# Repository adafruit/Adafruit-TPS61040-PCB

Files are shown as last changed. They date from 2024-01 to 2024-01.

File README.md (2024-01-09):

## Adafruit TPS61040 12V Bias Voltage Boost Converter PCB

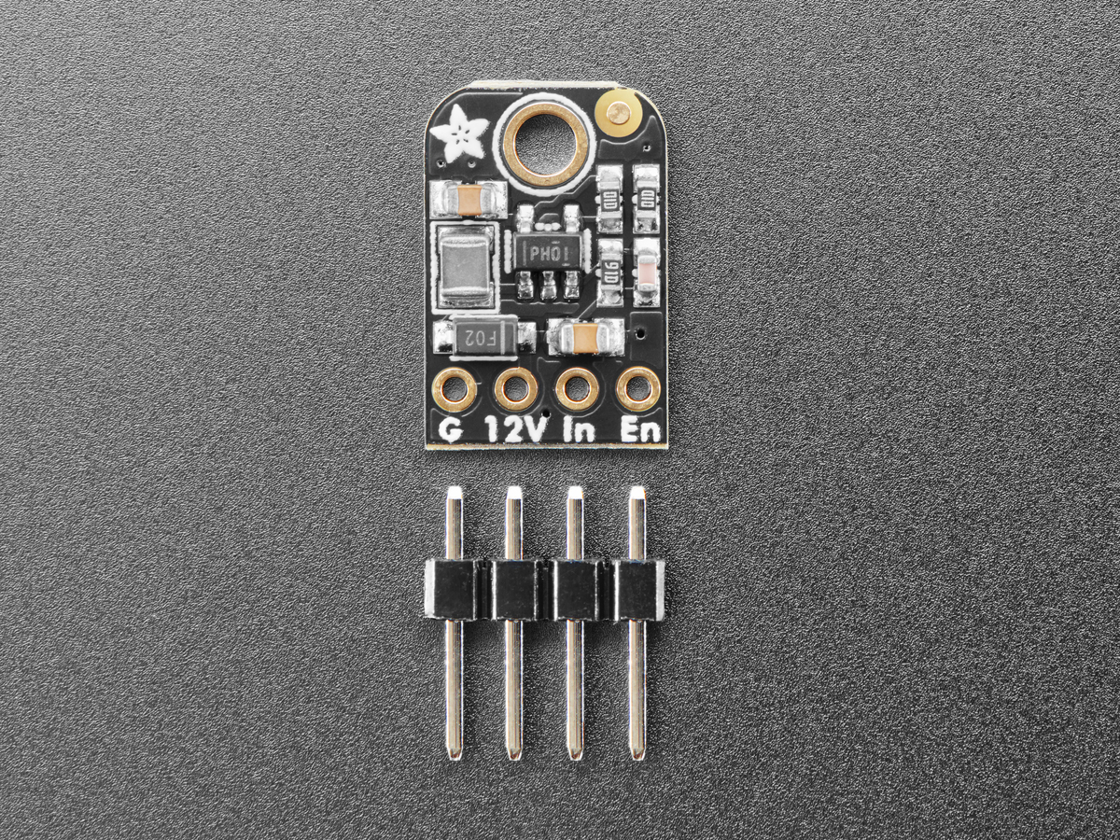
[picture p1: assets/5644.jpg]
<a href="http://www.adafruit.com/products/5644"><br/>
Click here to purchase one from the Adafruit shop</a>

PCB files for the Adafruit TPS61040 12V Bias Voltage Boost Converter. 

Format is EagleCAD schematic and board layout
* https://www.adafruit.com/product/5644

### Description

The Adafruit 12V Bias Voltage Boost Converter uses our new favorite mini-booster, the TI TPS61040, to generate a 12V DC from as little as 3V input. We use this chip a ton in our OLED boards, to generate the 12V bias voltage needed for the displays to function. But there's probably many other times and reasons you may want a high-ish voltage, such as driving an LED string backlight or re-programming FLASH or EEPROM memories.

Note that this board isn't good for high power driving, like solenoids or motors or long analog LED strips. You can get about 40mA out max. But definitely easier than getting a separate 12V supply when just a small amount of current is needed and you've already got 3.3 or 5V on the board.

You get one fully assembled breakout with a TPS61040 and required passive components, and a small bit of header. Give 2 to 6V DC on the IN and Ground pins. Then you'll have 12V on the 12V output pin. The Enable pin can be pulled low to disable the output.

### License

Adafruit invests time and resources providing this open source design, please support Adafruit and open-source hardware by purchasing products from [Adafruit](https://www.adafruit.com)!

Designed by Limor Fried/Ladyada for Adafruit Industries.

Creative Commons Attribution/Share-Alike, all text above must be included in any redistribution. 
See license.txt for additional details.

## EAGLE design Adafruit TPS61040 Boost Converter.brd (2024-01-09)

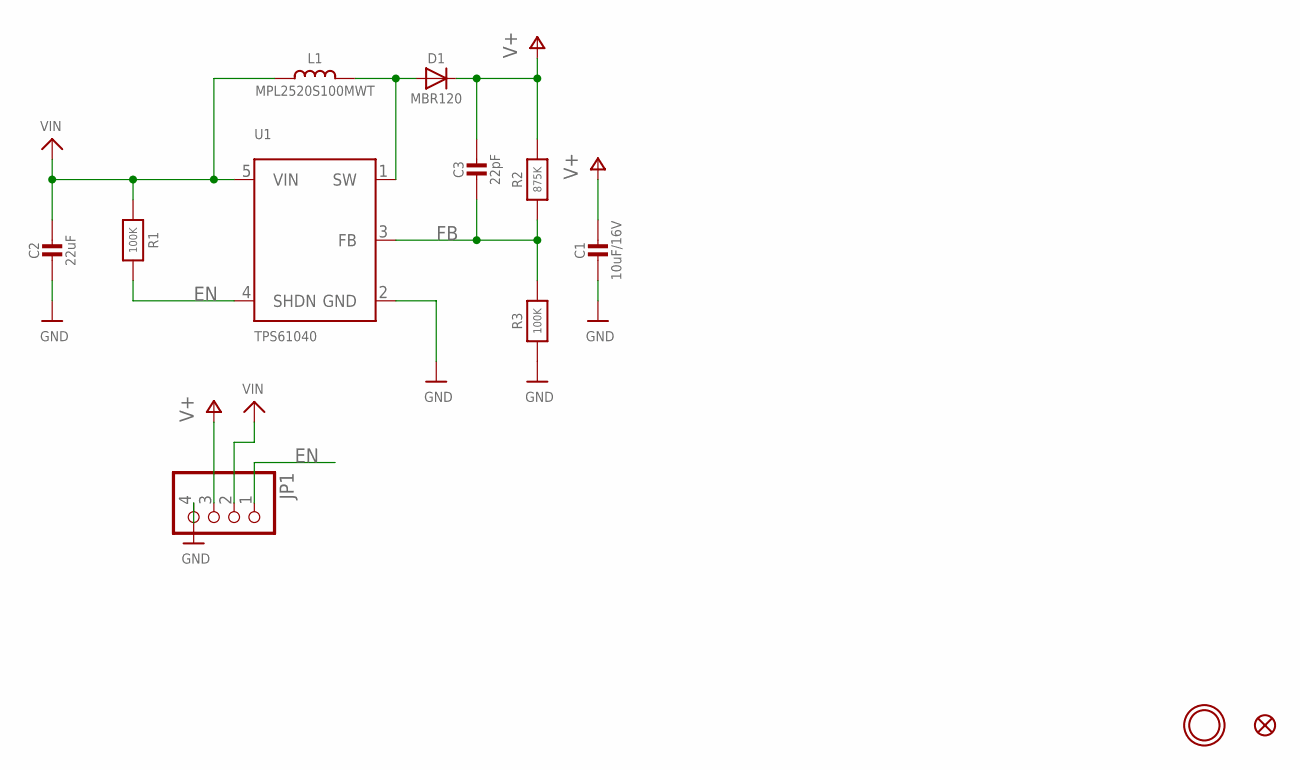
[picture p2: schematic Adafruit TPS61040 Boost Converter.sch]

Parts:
C1: 10uF/16V; 0805-NO
C2: 22uF; 0805-NO
C3: 22pF; 0603-NO
D1: MBR120; SOD-123FL
FID1: FIDUCIAL_1MM
JP1: HEADER-1X4ROUND; 1X04_ROUND
L1: MPL2520S100MWT; INDUCTOR_1007
R1, R3: 100K; 0603-NO
R2: 875K; 0603-NO
U1: TPS61040; SOT23-5
U$9: MOUNTINGHOLE2.5; MOUNTINGHOLE_2.5_PLATED

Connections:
EN: JP1.1, R1.2, U1.4 (SHDN)
FB: C3.2, R2.1, R3.2, U1.3 (FB)
GND: C1.2, C2.2, JP1.4, R3.1, U1.2 (GND)
unnamed: D1.A, L1.P$2 (2), U1.1 (SW)
V+: C1.1, C3.1, D1.C, JP1.3, R2.2
VIN: C2.1, JP1.2, L1.P$1 (1), R1.1, U1.5 (VIN)

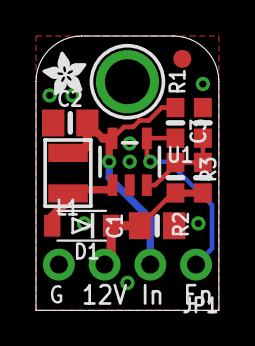
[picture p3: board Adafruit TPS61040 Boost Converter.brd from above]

Board: 2 copper layers, 10.2 x 15.2 mm, 14 parts (1 on the bottom side), 6 nets.

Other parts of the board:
U$10: PCBFEAT-REV-040
U$11: ADAFRUIT_2.5MM

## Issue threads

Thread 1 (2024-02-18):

Switch C3/R2 for easier customization?

WestfW, 2024-02-18:
If you switched C3 and R2 on the PCB, it would be slightly easier to customize the board for other output voltages (by changing the R2/R3 voltage divider (perhaps only one of them.)  (The switch would put both resistors near the edge of the board, where they would be slightly easier to replace.)

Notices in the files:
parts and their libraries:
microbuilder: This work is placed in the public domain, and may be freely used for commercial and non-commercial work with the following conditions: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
